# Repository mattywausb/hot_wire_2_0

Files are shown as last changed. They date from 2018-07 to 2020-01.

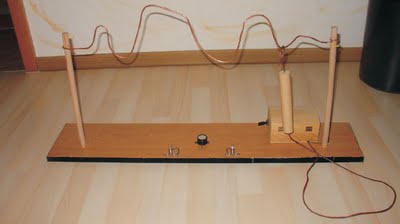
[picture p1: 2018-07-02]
demo/Heißer_draht_perfekt.JPG

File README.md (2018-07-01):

# hot_wire_2_0
Arduino project for a "hot wire" game.

"hot wire" is a game of agility, featuring a strong wire that goes throug a wireloop. The wire is bent in a tricky shape and is mounted to a frame to hold it in the air. The wireloop has a handle.
The challange is to move the loop from one side of the wire to the other side without touching the wire.

Normally this is implemented very simple with a battery, a light and a buzzer. Loop and wire work as a switch, so touching the wire with the loop will light up the lamp and start the buzzer. When playing the game, there is a limit of touches until you have lost. 

This concept exists for decades an has some drawbacks I want to eliminate:

* if a short touch or two touches right after another is counted as a failure depends on the person supervising the game
* also, if a long touch may count as multple failures depends on the supervisor
* Counting touches is done manually
* Everybody nearby the game gets annoyed by the buzzer, when staying for longer (this normally hits the supervisor first)

Target of this project is a new "pimped" version of the game without loosing the primary challenge.

* Automatic detection and counting of touches
* Replace the buzzer with visual and haptic feedback to the player (Led's on the loop, Vibration motor in the handle)
* Posibility to select from multiple difficulties
* Clear and rewarding feedback for win/loss

To implement this, I chose to use an arduino uno.

Lets go

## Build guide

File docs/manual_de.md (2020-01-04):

# Heißer Draht 2.0 -  Spiel und Betriebsanleitung

## Bestandteile
* Heißer Draht Aufbau mit Anschlusskabel
* Steuergerät mit LED Anzeige und Lautsprecher
* USB Powerbank und USB Kabel

## Aufbau
1. Anschlusskabel vom Aufbau an das Steuergerät stecken
2. USB Powerbank an das Steuergerät anschließen

Abbau in ungekehrter Reihenfolge

## Spielregeln
1. Das Spiel besteht aus einem "Heißen Draht" an dessen beiden Enden zwei Ablagen markiert sind sowie einer an einem Stab geführten Drahtschlaufe
2. Die Drahtschlaufe muss von einer Ablage zur anderen Seite geführt werden, ohne den Draht zu berühren
3. Jede Berührung führt zu einer "Aufladung" und die Lämpchen am Steuergerät färben sich Stück für Stück von grün nach rot
4. Kann die Schlaufe am Ziel abgelegt werden bevor alle Lämpchen rot sind, ist das Spiel gewonnen

## Spielstufen
(1) Einfach: Die Lämpchen laden sich nicht so schnell auf, und wenn sie nicht ganz rot gefärbt sind, erholen sie sich auch wieder

(2) Normal: Die Lämpchen laden sich recht zügig auf und erholen sich nicht

(3) Schwer: Die Lämpchen laden sich auch über die Zeit von alleine auf, d.h. man muss sich wirklich beeilen

## Spielablauf

###Spielstufe einstellen
Zu diesem Zweck muss die Schlaufe in einem der beiden Zielbereiche Kontakt haben. (Ist dies nicht der Fall, wird dies entweder durch blinkende violette Lämpchen angezeigt, oder grüne Lämpchen zeigen an, das ein Spiel läuft . In beiden Fällen, die Schlaufe einfach wieder auf den nächsten Startplatz legen. Sollte das Spiel nicht sofort enden, weil die Schlaufe bereits 10 Sekunden angehoben war, 10 Sekunden warten)

Pulsierende Himmelblaue Lampen zeigen die eingestellte Stufe an. (Jeweils zwei Lampen stehen für eine Stufe).

Über den Taster am Steuergerät wird durch die Spielstufen geschaltet.

###Spiel starten
Sowie die Schlaufe von der Startablage gehoben wird, beginnt das Spiel mit der gewählten Spielstufe zu laufen. Die Anzeige wird zuerst mit allen Lampen grün sein.
Bei jeder Berührung der Schlaufe mit dem heißen Draht werden alle Lampen weiß und ein Lämpchen verfärbt sich von grün über gelb nach rot. 

###Spiel gewinnen
Sowie die Schlaufe die Zielablage berührt ist das Spiel gewonnen. Es wird ein grünes Lauflicht angezeigt und kurz darauf die verbleibenden Lämpchen.

###Spiel verlieren
Ist auch das letzte Lämpchen rot gefärbt, ist das Spiel verloren und die gesamte Anzeige flackert mit roten Lämpchen. Die Schlaufe kann jetzt "gefahrlos" bis zur nächsten Ablage geführt und abgelegt werden. 

### Ablage prüfen
Nach der Anzeige der Spielergebnisses wartet das Spiel, bis die Schlaufe wieder auf eine der Ablagen gelegt wurde. Dies wird durch zwei blinkende lila Lämpchen angezeigt. Wird in dieser Phase der heiße Draht von der Schlaufe berührt, so wird dies mit zwei gelben Lämpchen in der Mitte angezeigt.

Ist die Schlaufe auf eine Ablage, geht es von Vorne los mit "Spielstufe einstellen".

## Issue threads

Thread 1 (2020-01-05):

Bad Sound Quality because of interference with pixel string

mattywausb, 2020-01-05:
Need some improvement in the circuit to prevent interference

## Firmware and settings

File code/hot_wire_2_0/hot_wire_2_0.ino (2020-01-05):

#include "mainSettings.h"

#ifdef TRACE_ON
#define TRACE_MODES
//#define TRACE_SCORE
#endif

enum PROCESS_MODES {
  IDLE_MODE, 
  GAME_MODE,
  WIN_MODE,
  LOSS_MODE,
  SETUP_MODE
};


PROCESS_MODES g_process_mode = SETUP_MODE; 

/* current game setting */

#define FOUL_LIMIT 32000
#define RESTART_THRESHOLD 10000

int g_current_difficulty=1;

/* current game state */
unsigned long foul_detect_interval=0;
int foul_speed=0;
int foul_fallback_rate=0;
int foul_counter=0;
int foul_autoincrement=0;
unsigned long game_frame_start_time=0;
unsigned long foul_current_cumulation=0;
unsigned long mode_time_sync_register=0;
boolean foul_running=false;
int start_zone=-4;
int finish_zone=-4;

#define GAME_FRAME_DURATION 100

void setup() 
{

  #ifdef TRACE_ON 
    char compile_signature[] = "--- START (Build: " __DATE__ " " __TIME__ ") ---";   
    Serial.begin(9600);
    Serial.println(compile_signature); 
  #endif

  
  output_led_setup();
  sound_setup();
  input_setup();

  enter_SETUP_MODE();
}

void loop() 
{
   input_switches_scan_tick();
   input_zone_scan_tick();
   switch(g_process_mode) {
    case SETUP_MODE: process_SETUP_MODE();break;
    case IDLE_MODE: process_IDLE_MODE();break;
    case GAME_MODE:process_GAME_MODE();break;
    case WIN_MODE:process_WIN_MODE();break;
    case LOSS_MODE:process_LOSS_MODE();break;
   } // switch
   sound_tick();
} 

/* ======== SETUP_MODE ========*/

/* Wait until loop gets placed on one landing contact */

void enter_SETUP_MODE()
{
   #ifdef TRACE_MODES
      Serial.print(F("#SETUP_MODE: "));
      Serial.print(freeMemory());
      Serial.print(F(" bytes free memory. "));
      Serial.print(millis()/1000);
      Serial.println(F(" seconds uptime"));
    #endif
    g_process_mode=SETUP_MODE;
    foul_counter=0;
   
}

void process_SETUP_MODE()
{
  int zone=input_get_contact_zone();
  if(zone==ZONE_LANDING_1 || zone==ZONE_LANDING_2) {
    if (input_get_contact_state_duration()>100) {
      start_zone=zone;
      finish_zone= start_zone==ZONE_LANDING_1 ? ZONE_LANDING_2 : ZONE_LANDING_1;
      enter_IDLE_MODE();
      return;
    }
  }
  if(zone==ZONE_HOT) {
    sound_start_beep();
  } else {
   sound_stop();
  }
  output_scene_setup();
}
/* ======== IDLE_MODE ========*/

void enter_IDLE_MODE()
{
   #ifdef TRACE_MODES
      Serial.print(F("#IDLE_MODE: "));
      Serial.print(freeMemory());
      Serial.print(F(" bytes free memory. "));
      Serial.print(millis()/1000);
      Serial.println(F(" seconds uptime"));
    #endif
    g_process_mode=IDLE_MODE;
     sound_start_GameStartMelody();
}

void process_IDLE_MODE()
{
   if(input_selectGotPressed()) 
   {
      if(++g_current_difficulty>=3)g_current_difficulty=0;
      return;
   }

   if(input_get_contact_zone()==ZONE_NONE && input_get_contact_state_duration()>100) {
    enter_GAME_MODE();
    return;
   }
   output_scene_idle();
}

/* ======== GAME_MODE ========*/

void enter_GAME_MODE()
{
   #ifdef TRACE_MODES
      Serial.print(F("#GAME_MODE: "));
      Serial.print(freeMemory());
      Serial.print(F(" bytes free memory. "));
      Serial.print(millis()/1000);
      Serial.println(F(" seconds uptime"));
    #endif
    g_process_mode=GAME_MODE;
    unsigned long foul_detect_interval=0;
    foul_detect_interval=1;
    foul_speed=1000;
    foul_fallback_rate=0;
    foul_counter=0;
    foul_running=false;
    foul_autoincrement=0;
    foul_current_cumulation=0;
    game_frame_start_time=mode_time_sync_register=millis();
    switch (g_current_difficulty) {
      case 0:
        foul_detect_interval=500;
        foul_autoincrement=0;
        foul_speed=4;
        foul_fallback_rate=50;
        break;
      case 1:
        foul_detect_interval=300;
        foul_autoincrement=0;
        foul_speed=7;
        foul_fallback_rate=0;
        break;
      case 2:
        foul_detect_interval=150;
        foul_autoincrement=60;
        foul_speed=7;
        foul_fallback_rate=0;
        break;
    }
}

void process_GAME_MODE()
{
  if(input_get_contact_zone()==start_zone&& (millis()-mode_time_sync_register<RESTART_THRESHOLD || input_get_contact_state_duration()>RESTART_THRESHOLD)) {
    enter_IDLE_MODE();
    return;
  }
  
  if(input_get_contact_zone()==ZONE_HOT && input_get_contact_state_duration()>foul_detect_interval) {
    foul_running=true;
    foul_current_cumulation=(input_get_contact_state_duration()-foul_detect_interval)*foul_speed;
    
    #ifdef TRACE_SCORE
        Serial.print(F(">TRACE_SCORE"));
        Serial.println(foul_current_cumulation+foul_counter);
    #endif
  } else foul_running=false;

  if(input_get_contact_zone()==ZONE_HOT) {
    sound_start_beep();
  } else {
    sound_stop();
  }

  if(millis()-game_frame_start_time>GAME_FRAME_DURATION) {
    game_frame_start_time=millis();
    foul_counter+=foul_autoincrement;  // Manage autoincrement
    if(foul_fallback_rate>0) {          // Manage fallback
      int pixel_remainder=foul_counter%output_get_pixel_foul_amount();
      if( pixel_remainder>0) 
          if(foul_fallback_rate<pixel_remainder) foul_counter-=foul_fallback_rate;
          else foul_counter-=pixel_remainder;
    }
  }

  if(foul_current_cumulation+foul_counter>FOUL_LIMIT) {
      enter_LOSS_MODE();
      return;
  }
    
  if(input_get_contact_zone()!=ZONE_HOT && foul_current_cumulation>0) {
    foul_counter+=foul_current_cumulation;
    foul_current_cumulation=0;
    #ifdef TRACE_SCORE
        Serial.println(F(">TRACE_SCORE - contact ended"));
    #endif
  }

  if(input_get_contact_zone()==finish_zone) {
    enter_WIN_MODE();
    return;
  }

  output_scene_game();
}

/* ======== WIN_MODE ========*/

void enter_WIN_MODE()
{
   #ifdef TRACE_MODES
      Serial.print(F("#WIN_MODE: "));
      Serial.print(freeMemory());
      Serial.print(F(" bytes free memory. "));
      Serial.print(millis()/1000);
      Serial.println(F(" seconds uptime"));
    #endif
    g_process_mode=WIN_MODE;
    mode_time_sync_register=millis();
    sound_start_GameOverMelody();
}


void process_WIN_MODE()
{
  if(millis()-mode_time_sync_register > 15000 || input_selectGotPressed()) 
  {
    enter_SETUP_MODE();
  }

  output_scene_win(millis()-mode_time_sync_register);
}

/* ======== LOSS_MODE ========*/

void enter_LOSS_MODE()
{
   #ifdef TRACE_MODES
      Serial.print(F("#LOSS_MODE: "));
      Serial.print(freeMemory());
      Serial.print(F(" bytes free memory. "));
      Serial.print(millis()/1000);
      Serial.println(F(" seconds uptime"));
    #endif
    g_process_mode=LOSS_MODE;
    mode_time_sync_register=millis();
    sound_start_Crash();
}

void process_LOSS_MODE()
{
  if(millis()-mode_time_sync_register > 10000 || input_selectGotPressed()) 
  {
    enter_SETUP_MODE();
  }
  output_scene_loss(millis()-mode_time_sync_register);
}

/* ******************** Memory Helper *************** */
 
#ifdef __arm__
// should use uinstd.h to define sbrk but Due causes a conflict
extern "C" char* sbrk(int incr);
#else  // __ARM__
extern char *__brkval;
#endif  // __arm__

int freeMemory() {
  char top;
#ifdef __arm__
  return &top - reinterpret_cast<char*>(sbrk(0));
#elif defined(CORE_TEENSY) || (ARDUINO > 103 && ARDUINO != 151)
  return &top - __brkval;
#else  // __arm__
  return __brkval ? &top - __brkval : &top - __malloc_heap_start;
#endif  // __arm__
}

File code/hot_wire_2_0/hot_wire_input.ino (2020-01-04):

/* Functions to handle all input elements */

#include "mainSettings.h"

// Activate general trace output

#ifdef TRACE_ON
#define TRACE_INPUT 
//#define TRACE_INPUT_HIGH
//#define TRACE_INPUT_TIMING 
#endif

const unsigned long contact_debounce_tolerance = 500; // milliseconds


/* Button constants */ 
const byte digi_pin_list[] = {2,    // Mode Select 
                               };
#define INPUT_PORT_COUNT sizeof(digi_pin_list)
#define INPUT_BUTTON_COOLDOWN 10   // Milliseconds until we accept the next state change of an input

                             

/* Button variables */

unsigned long buttons_last_read_time=0;  // Millis at last buttoncheck
unsigned int button_raw_state=0;         // state of buttons in last button check
unsigned int button_tick_state = 0;      // current and historized state in the actual tick

/* Generic button bit pattern (Button = 0) */

#define INPUT_0_BITS 0x0003
#define INPUT_0_IS_ON_PATTERN 0x0003
#define INPUT_0_SWITCHED_ON_PATTERN 0x0001
#define INPUT_0_SWITCHED_OFF_PATTERN 0x0002


/* Element specific  button bit pattern */
/*                                         76543210 */

#define INPUT_BUTTON_A_BITS                 0x0003
#define INPUT_BUTTON_A_IS_PRESSED_PATTERN   0x0003
#define INPUT_BUTTON_A_GOT_PRESSED_PATTERN   0x0001
#define INPUT_BUTTON_A_GOT_RELEASED_PATTERN  0x0002

#define INPUT_ALL_BUTTON_STATE_MASK 0x0003


/* history handling */

#define INPUT_CURRENT_BITS 0x0005
#define INPUT_PREVIOUS_BITS 0x000a


unsigned long last_press_start_time=0;
unsigned long last_press_end_time=0;
bool input_enabled=true;

/* General state variables */
unsigned long input_last_change_time = 0;


/* Analog Input Handling */
#define VOLTAGE_PIN 12
const byte zone_pin_list[] = {0,1,2 };    // hot wire, Landing 1, landing 2

#define ZONE_COUNT sizeof(zone_pin_list)
#define ANALOG_HIGH_THRESHOLD 512
#define ANALOG_COOLDOWN_INTERVAL 70 
unsigned long analog_prev_measure_time = 0;
unsigned long analog_contact_start_time = 0;
unsigned long analog_contact_end_time = 0;
int analog_current_zone=-1;



/* ********************************************************************************************************** */
/*               Interface functions                                                                          */

/* ------------- Button events --------------- */

bool input_selectGotPressed()
{

  return input_enabled && ((button_tick_state & INPUT_BUTTON_A_BITS) == INPUT_BUTTON_A_GOT_PRESSED_PATTERN);
}

bool input_selectIsPressed()
{
  return input_enabled && ((button_tick_state & INPUT_BUTTON_A_BITS) == INPUT_BUTTON_A_IS_PRESSED_PATTERN); 
}

byte input_selectGotReleased()
{
  return input_enabled && ((button_tick_state & INPUT_BUTTON_A_BITS) == INPUT_BUTTON_A_GOT_RELEASED_PATTERN); 
}

long input_getCurrentPressDuration()
{
  #ifdef TRACE_INPUT_TIMING
    Serial.print(F("TRACE_INPUT_TIMING:input CurrentPressDuration:"));
    Serial.println(millis()-last_press_start_time);
  #endif
    
  return millis()-last_press_start_time;
}

long input_getLastPressDuration()
{
  return  last_press_end_time-last_press_start_time;
}


int input_get_contact_zone()  {return analog_current_zone;}

unsigned long input_get_contact_state_duration() 
{
  return analog_contact_end_time-analog_contact_start_time;
}


/* ------------- Operations ----------------- */



/* Disable input until all buttons have been released */

void input_IgnoreUntilRelease()
{
  input_enabled=false;
}


/* ************************************* TICK ***********************************************
   translate the state of buttons into the ticks of the master loop
   Must be called by the master loop for every cycle to provide valid event states of
   all input devices.
   Also transfers state changes, tracked with the timer interrupt into a tick state
*/

void input_switches_scan_tick()
{
  bool change_happened=false;
  
  /* put regular button scan into buttow_raw_state*/
  if (millis() - buttons_last_read_time > INPUT_BUTTON_COOLDOWN)
  {
    byte isPressed=0;
    int analog_value=0;
    buttons_last_read_time = millis();
    
    for (int i = 0; i <INPUT_PORT_COUNT; i++) { // for all input ports configured
      isPressed=!digitalRead(digi_pin_list[i]);
      bitWrite(button_raw_state,i*2,isPressed);  
    }
  }

  /* copy previous tick  state to history bits  and take raw pattern as new value */
  button_tick_state = (button_tick_state & INPUT_CURRENT_BITS) << 1
               | (button_raw_state & INPUT_CURRENT_BITS);

  
  /* Track pressing time */
  for (int i =0;i<INPUT_PORT_COUNT;i++)
  {
    if((button_tick_state & (INPUT_0_BITS<<(i*2))) == INPUT_0_SWITCHED_ON_PATTERN<<(i*2)) 
    {
      change_happened=true;
      last_press_end_time =last_press_start_time=millis();
      #ifdef TRACE_INPUT_HIGH
        Serial.print(("TRACE_INPUT_HIGH:press of "));Serial.println(i);
      #endif     
    }
    if((button_tick_state & (INPUT_0_BITS<<(i*2))) == INPUT_0_SWITCHED_OFF_PATTERN<<(i*2)) 
    {
      last_press_end_time=millis();
      change_happened=true;
      #ifdef TRACE_INPUT_HIGH
        Serial.print(("TRACE_INPUT_HIGH:release of "));Serial.println(i);
      #endif     
    }
  }

  if((button_tick_state & INPUT_ALL_BUTTON_STATE_MASK) ==0x00)  input_enabled=true; // enable input when all is released and settled

  if(change_happened)input_last_change_time = millis(); // Reset the globel age of interaction
} // void input_switches_tick()


/* essential wire test, returns number of the wire, when there is contact or -1 if there is no contact -2 if there are ambiguos readings */

void input_zone_scan_tick()
{ 
   if(millis()-analog_prev_measure_time< ANALOG_COOLDOWN_INTERVAL) return;  // Provide previous result until cooldown is over
   analog_prev_measure_time=millis();
   
   int zone;
   byte analogHigh;
   /* check for false contacts */
   digitalWrite(VOLTAGE_PIN,LOW);  
   for(zone=0;zone<ZONE_COUNT;zone++) {      
      analogHigh=analogRead(zone)>ANALOG_HIGH_THRESHOLD;
      if(analogHigh) return -2;   // since we dont provide voltage yet, there should be no reading
   }

   /* Now check for real contact */
   digitalWrite(VOLTAGE_PIN,HIGH);  
   for(zone=0;zone<ZONE_COUNT;zone++) {      
      analogHigh=analogRead(zone)>ANALOG_HIGH_THRESHOLD;
      if(analogHigh) break;  
   }
   if(zone>=ZONE_COUNT) zone=-1;  // Set to -1 if no contact is detected;

   /* Manage the time tracking */
   if(zone!=analog_current_zone) {
      analog_contact_start_time=analog_contact_end_time=analog_prev_measure_time; 
      analog_current_zone=zone;
   } else {
     analog_contact_end_time=analog_prev_measure_time;
   }
   return ;
}


/* ***************************       S E T U P           ******************************
*/
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

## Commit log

2018-07-01 fritz schema created
    [hot wire.fzz]
2018-07-02 Start Modularizing
    [hot wire.fzz]
2018-07-03 PLatinenlayout for Uno shield
    [hot wire.fzz]
2020-01-02 Redesigned circute to use neopixel led
    [hot wire.fzz]
